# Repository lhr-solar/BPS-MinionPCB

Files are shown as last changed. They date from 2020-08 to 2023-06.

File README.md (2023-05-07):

# BPS Voltage Temperature Minion PCB

## Purpose
This board communicates with the [Leader Board](https://github.com/lhr-solar/BPS-LeaderPCB) over ISOSPI. It is capable of reading up to 12 voltage measurements and 16 temperature measurements. It is also capable of implementing battery balancing through the LTC6811.

## Connectors
* Two 10 pin headers that are used to place the [Minion Hat Board](https://github.com/lhr-solar/BPS-MinionShieldPCB) on top
* Two 7 pin connectors that are used to connect the voltage taps to the board
* Two 2 pin connectors for ISOSPI communication

## BOM
[Mouser cart](https://www.mouser.com/ProjectManager/ProjectDetail.aspx?AccessID=1d4073bff4) of all the components that cannot be sampled.

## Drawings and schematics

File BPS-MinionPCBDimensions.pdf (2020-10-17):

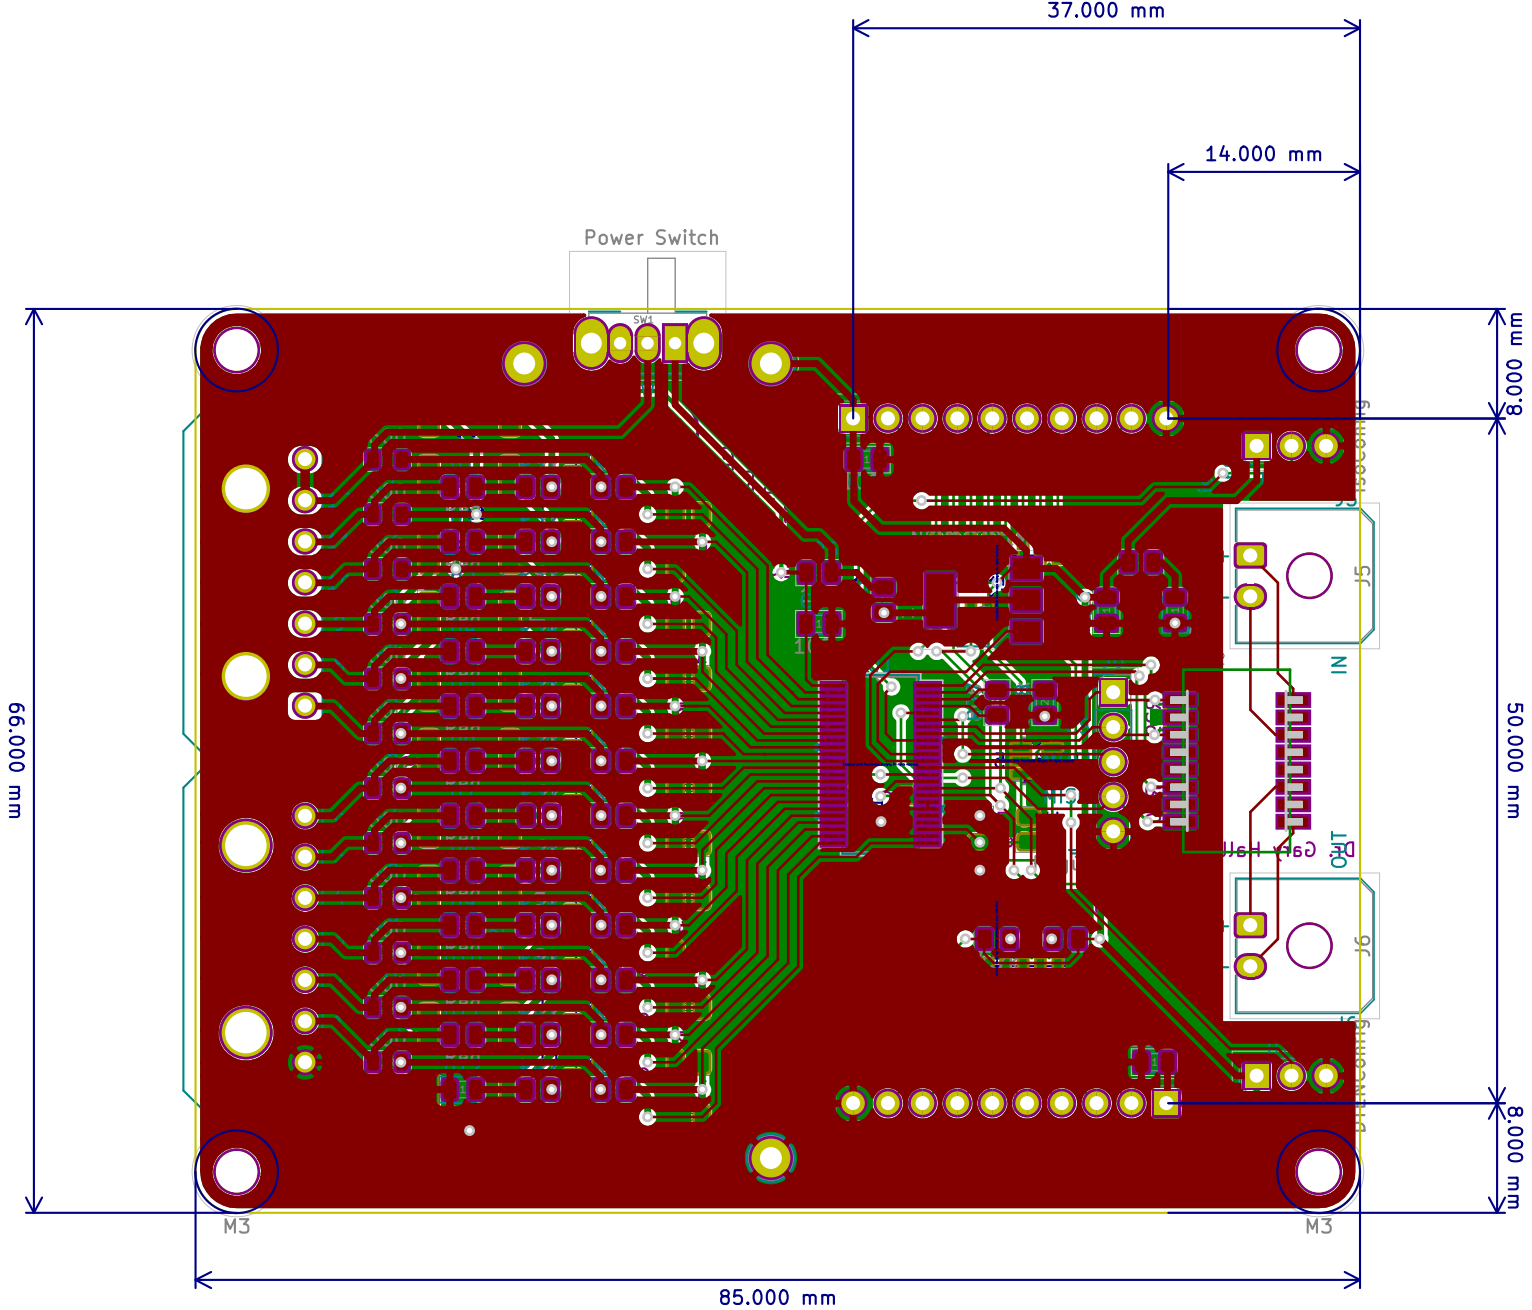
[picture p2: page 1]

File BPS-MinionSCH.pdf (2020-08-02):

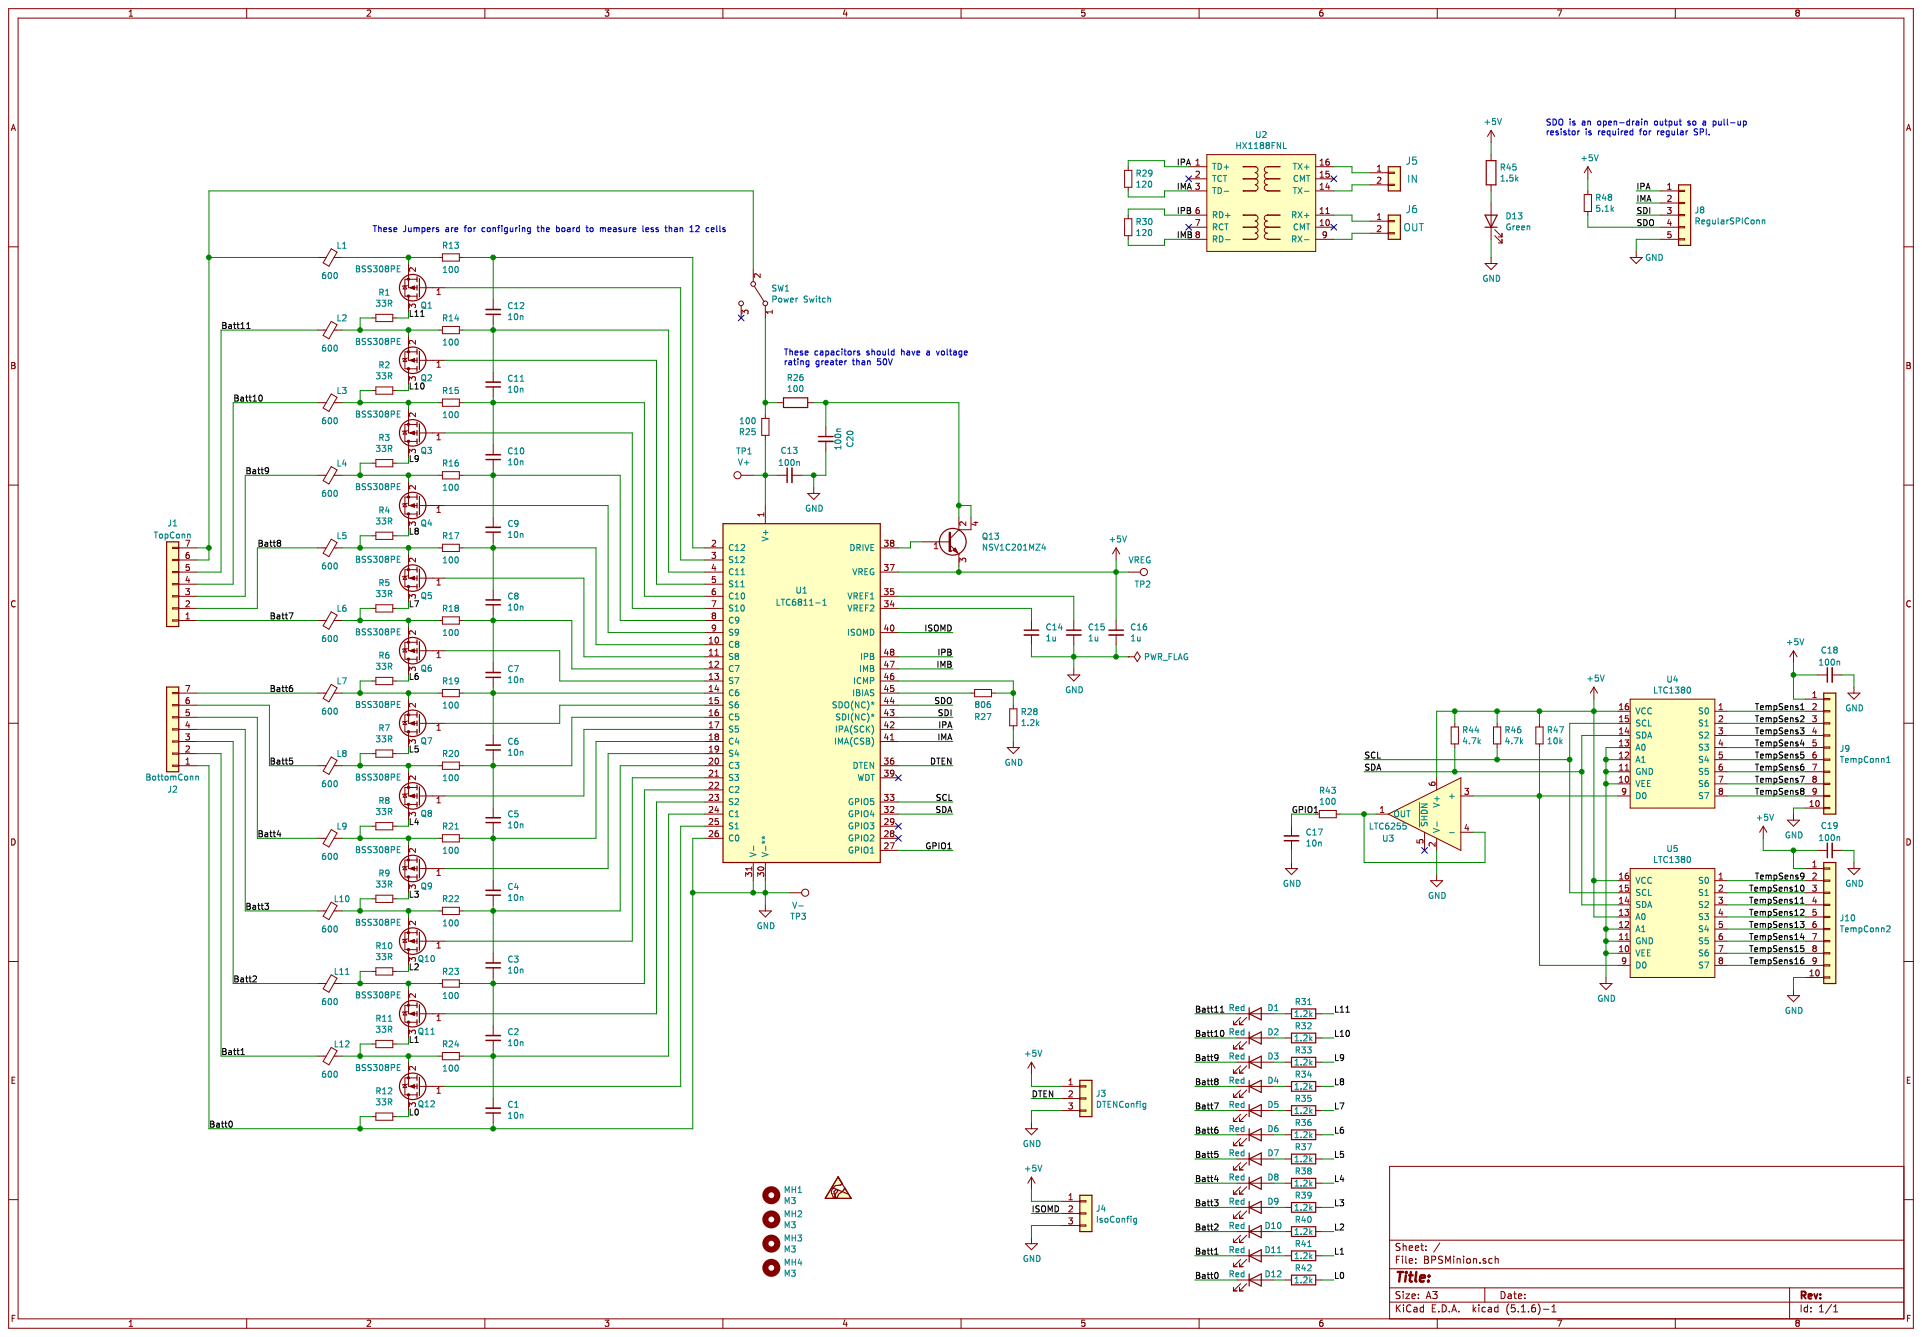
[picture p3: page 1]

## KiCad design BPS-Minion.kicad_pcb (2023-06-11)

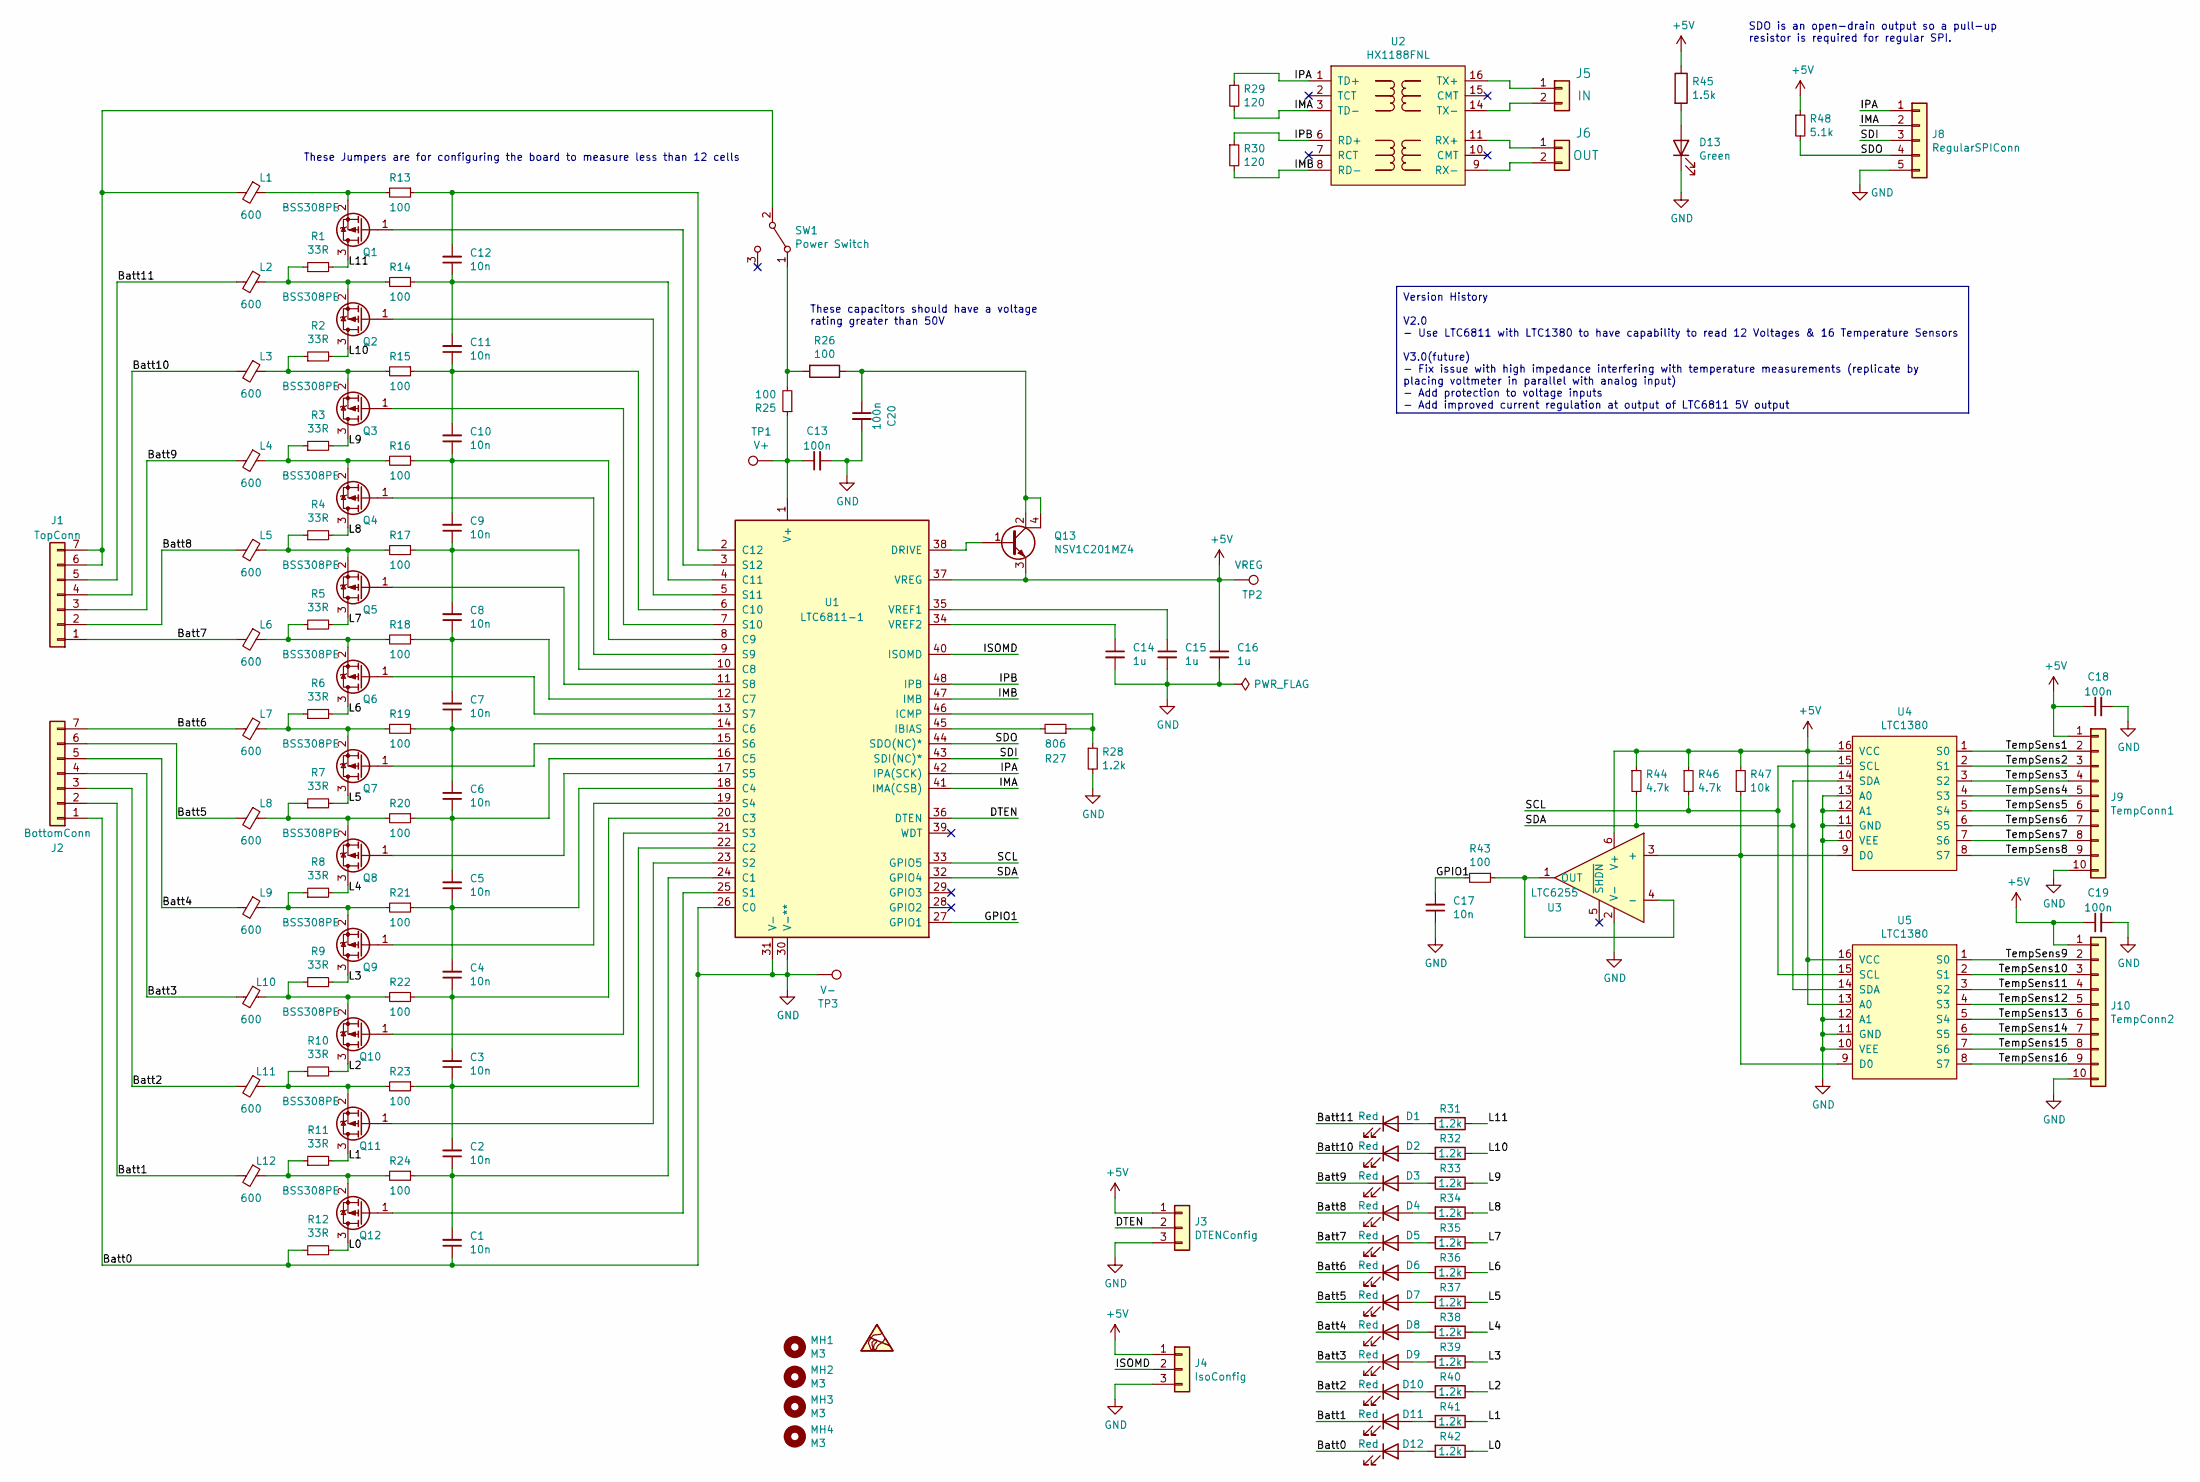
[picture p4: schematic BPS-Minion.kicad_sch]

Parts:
C1, C2, C3, C4, C5, C6, C7, C8, C9, C10, C11, C12, C17: 10n; C_0805_2012Metric
C13, C20: 100n; C_0805_2012Metric; Tolerance 10%; Voltage 100VDC
C14, C15: 1u; C_0805_2012Metric; Tolerance 10%; Voltage 50VDC
C16: 1u; C_0805_2012Metric
C18, C19: 100n; C_0805_2012Metric; Tolerance 10%; Voltage 50VDC
D1, D2, D3, D4, D5, D6, D7, D8, D9, D10, D11, D12: Red; LED_0805_2012Metric
D13: Green; LED_0805_2012Metric
J1: TopConn; Molex_Micro-Fit_3.0_43650-0700_1x07_P3.00mm_Horizontal
J2: BottomConn; Molex_Micro-Fit_3.0_43650-0700_1x07_P3.00mm_Horizontal
J3: DTENConfig; PinHeader_1x03_P2.54mm_Vertical
J4: IsoConfig; PinHeader_1x03_P2.54mm_Vertical
J5: IN; Molex_Micro-Fit_3.0_43650-0200_1x02_P3.00mm_Horizontal
J6: OUT; Molex_Micro-Fit_3.0_43650-0200_1x02_P3.00mm_Horizontal
J8: RegularSPIConn; PinHeader_1x05_P2.54mm_Vertical
J9: TempConn1; PinHeader_1x10_P2.54mm_Vertical
J10: TempConn2; PinHeader_1x10_P2.54mm_Vertical
L1, L2, L3, L4, L5, L6, L7, L8, L9, L10, L11, L12: 600; L_0805_2012Metric
MH1, MH2, MH3, MH4: M3; MountingHole_3mm
Q1, Q2, Q3, Q4, Q5, Q6, Q7, Q8, Q9, Q10, Q11, Q12: BSS308PE; SOT-23
Q13: NSV1C201MZ4; SOT-223
R1, R2, R3, R4, R5, R6, R7, R8, R9, R10, R11, R12: 33R; R_2512_6332Metric
R13, R14, R15, R16, R17, R18, R19, R20, R21, R22, R23, R24, R25, R26, R43: 100; R_0805_2012Metric
R27: 806; R_0805_2012Metric
R28, R31, R32, R33, R34, R35, R36, R37, R38, R39, R40, R41, R42: 1.2k; R_0805_2012Metric
R29, R30: 120; R_0805_2012Metric
R44, R46: 4.7k; R_0805_2012Metric
R45: 1.5k; R_0805_2012Metric
R47: 10k; R_0805_2012Metric
R48: 5.1k; R_0805_2012Metric
SW1: Power Switch; SW_CuK_OS102011MA1QN1_SPDT_Angled
TP1: V+; TestPoint_Keystone_5005-5009_Compact
TP2: VREG; TestPoint_Keystone_5005-5009_Compact
TP3: V-; TestPoint_Keystone_5005-5009_Compact
U1: LTC6811-1; LTC6811HG-1-PBF
U2: HX1188FNL; HXXXX
U3: LTC6255; LTC6255CS6-TRMPBF
U4, U5: LTC1380; LTC1380CS-PBF

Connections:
+5V: C16.1, C18.1, C19.1, J3.1, J4.1, J9.1, J10.1, Q13.3 (E), R44.1, R45.1, R46.1, R47.1, R48.1, TP2.1, U1.37 (VREG), U3.6 (V+), U4.16 (VCC), U5.13 (A0), U5.16 (VCC)
/Batt1: D11.1 (K), J2.2, L12.2
/Batt2: D10.1 (K), J2.3, L11.2
/Batt3: D9.1 (K), J2.4, L10.2
/Batt4: D8.1 (K), J2.5, L9.2
/Batt5: D7.1 (K), J2.6, L8.2
/Batt6: D6.1 (K), J2.7, L7.2
/Batt7: D5.1 (K), J1.1, L6.2
/Batt8: D4.1 (K), J1.2, L5.2
/Batt9: D3.1 (K), J1.3, L4.2
/Batt10: D2.1 (K), J1.4, L3.2
/Batt11: D1.1 (K), J1.5, L2.2
/DTEN: J3.2, U1.36 (DTEN)
/GPIO1: C17.2, R43.2, U1.27 (GPIO1)
/IMA: J8.2, R29.2, U1.41 (IMA(CSB)), U2.3 (TD-)
/IMB: R30.2, U1.47 (IMB), U2.8 (RD-)
/IPA: J8.1, R29.1, U1.42 (IPA(SCK)), U2.1 (TD+)
/IPB: R30.1, U1.48 (IPB), U2.6 (RD+)
/ISOMD: J4.2, U1.40 (ISOMD)
/L0: Q12.3 (D), R12.2, R42.1
/L1: Q11.3 (D), R11.2, R41.1
/L2: Q10.3 (D), R10.2, R40.1
/L3: Q9.3 (D), R9.2, R39.1
/L4: Q8.3 (D), R8.2, R38.1
/L5: Q7.3 (D), R7.2, R37.1
/L6: Q6.3 (D), R6.2, R36.1
/L7: Q5.3 (D), R5.2, R35.1
/L8: Q4.3 (D), R4.2, R34.1
/L9: Q3.3 (D), R3.2, R33.1
/L10: Q2.3 (D), R2.2, R32.1
/L11: Q1.3 (D), R1.2, R31.1
/SCL: R46.2, U1.33 (GPIO5), U4.15 (SCL), U5.15 (SCL)
/SDA: R44.2, U1.32 (GPIO4), U4.14 (SDA), U5.14 (SDA)
/SDI: J8.3, U1.43 (SDI(NC)*)
/SDO: J8.4, R48.2, U1.44 (SDO(NC)*)
/TempSens1: J9.2, U4.1 (S0)
/TempSens2: J9.3, U4.2 (S1)
/TempSens3: J9.4, U4.3 (S2)
/TempSens4: J9.5, U4.4 (S3)
/TempSens5: J9.6, U4.5 (S4)
/TempSens6: J9.7, U4.6 (S5)
/TempSens7: J9.8, U4.7 (S6)
/TempSens8: J9.9, U4.8 (S7)
/TempSens9: J10.2, U5.1 (S0)
/TempSens10: J10.3, U5.2 (S1)
/TempSens11: J10.4, U5.3 (S2)
/TempSens12: J10.5, U5.4 (S3)
/TempSens13: J10.6, U5.5 (S4)
/TempSens14: J10.7, U5.6 (S5)
/TempSens15: J10.8, U5.7 (S6)
/TempSens16: J10.9, U5.8 (S7)
GND: C1.1, C13.2, C14.2, C15.2, C16.2, C17.1, C18.2, C19.2, C20.2, D12.1 (K), D13.1 (K), J2.1, J3.3, J4.3, J8.5, J9.10, J10.10, R12.1, R28.2, TP3.1, U1.26 (C0), U1.30 (V-**), U1.31 (V-), U3.2 (V-), U4.10 (VEE), U4.11 (GND), U4.12 (A1), U4.13 (A0), U5.10 (VEE), U5.11 (GND), U5.12 (A1)
unnamed: C1.2, C2.1, R24.1, U1.24 (C1)
unnamed: C2.2, C3.1, R23.1, U1.22 (C2)
unnamed: C3.2, C4.1, R22.1, U1.20 (C3)
unnamed: C4.2, C5.1, R21.1, U1.18 (C4)
unnamed: C5.2, C6.1, R20.1, U1.16 (C5)
unnamed: C6.2, C7.1, R19.1, U1.14 (C6)
unnamed: C7.2, C8.1, R18.1, U1.12 (C7)
unnamed: C8.2, C9.1, R17.1, U1.10 (C8)
unnamed: C9.2, C10.1, R16.1, U1.8 (C9)
unnamed: C10.2, C11.1, R15.1, U1.6 (C10)
unnamed: C11.2, C12.1, R14.1, U1.4 (C11)
unnamed: C12.2, R13.1, U1.2 (C12)
unnamed: C13.1, R25.1, TP1.1, U1.1 (V+)
unnamed: C14.1, U1.34 (VREF2)
unnamed: C15.1, U1.35 (VREF1)
unnamed: C20.1, Q13.2 (C), Q13.4 (C), R26.1
unnamed: D1.2 (A), R31.2
unnamed: D2.2 (A), R32.2
unnamed: D3.2 (A), R33.2
unnamed: D4.2 (A), R34.2
unnamed: D5.2 (A), R35.2
unnamed: D6.2 (A), R36.2
unnamed: D7.2 (A), R37.2
unnamed: D8.2 (A), R38.2
unnamed: D9.2 (A), R39.2
unnamed: D10.2 (A), R40.2
unnamed: D11.2 (A), R41.2
unnamed: D12.2 (A), R42.2
unnamed: D13.2 (A), R45.2
unnamed: J1.6, J1.7, L1.2, SW1.2 (B)
unnamed: J5.1, U2.16 (TX+)
unnamed: J5.2, U2.14 (TX-)
unnamed: J6.1, U2.11 (RX+)
unnamed: J6.2, U2.9 (RX-)
unnamed: L1.1, Q1.2 (S), R13.2
unnamed: L2.1, Q2.2 (S), R1.1, R14.2
unnamed: L3.1, Q3.2 (S), R2.1, R15.2
unnamed: L4.1, Q4.2 (S), R3.1, R16.2
unnamed: L5.1, Q5.2 (S), R4.1, R17.2
unnamed: L6.1, Q6.2 (S), R5.1, R18.2
unnamed: L7.1, Q7.2 (S), R6.1, R19.2
unnamed: L8.1, Q8.2 (S), R7.1, R20.2
unnamed: L9.1, Q9.2 (S), R8.1, R21.2
unnamed: L10.1, Q10.2 (S), R9.1, R22.2
unnamed: L11.1, Q11.2 (S), R10.1, R23.2
unnamed: L12.1, Q12.2 (S), R11.1, R24.2
unnamed: Q1.1 (G), U1.3 (S12)
unnamed: Q2.1 (G), U1.5 (S11)
unnamed: Q3.1 (G), U1.7 (S10)
unnamed: Q4.1 (G), U1.9 (S9)
unnamed: Q5.1 (G), U1.11 (S8)
unnamed: Q6.1 (G), U1.13 (S7)
unnamed: Q7.1 (G), U1.15 (S6)
unnamed: Q8.1 (G), U1.17 (S5)
unnamed: Q9.1 (G), U1.19 (S4)
unnamed: Q10.1 (G), U1.21 (S3)
unnamed: Q11.1 (G), U1.23 (S2)
unnamed: Q12.1 (G), U1.25 (S1)
unnamed: Q13.1 (B), U1.38 (DRIVE)
unnamed: R25.2, R26.2, SW1.1 (A)
unnamed: R27.1, R28.1, U1.46 (ICMP)
unnamed: R27.2, U1.45 (IBIAS)
unnamed: R43.1, U3.1 (OUT), U3.4 (-)
unnamed: R47.2, U3.3 (+), U4.9 (D0), U5.9 (D0)

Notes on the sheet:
Version History V2.0 - Use LTC6811 with LTC1380 to have capability to read 12 Voltages & 16 Temperature Sensors V3.0(future) - Fix issue with high impedance interfering with temperature measurements (replicate by placing voltmeter in parallel with analog input) - Add protection to voltage inputs - 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
These Jumpers are for configuring the board to measure less than 12 cells
SDO is an open-drain output so a pull-up resistor is required for regular SPI.
These capacitors should have a voltage rating greater than 50V

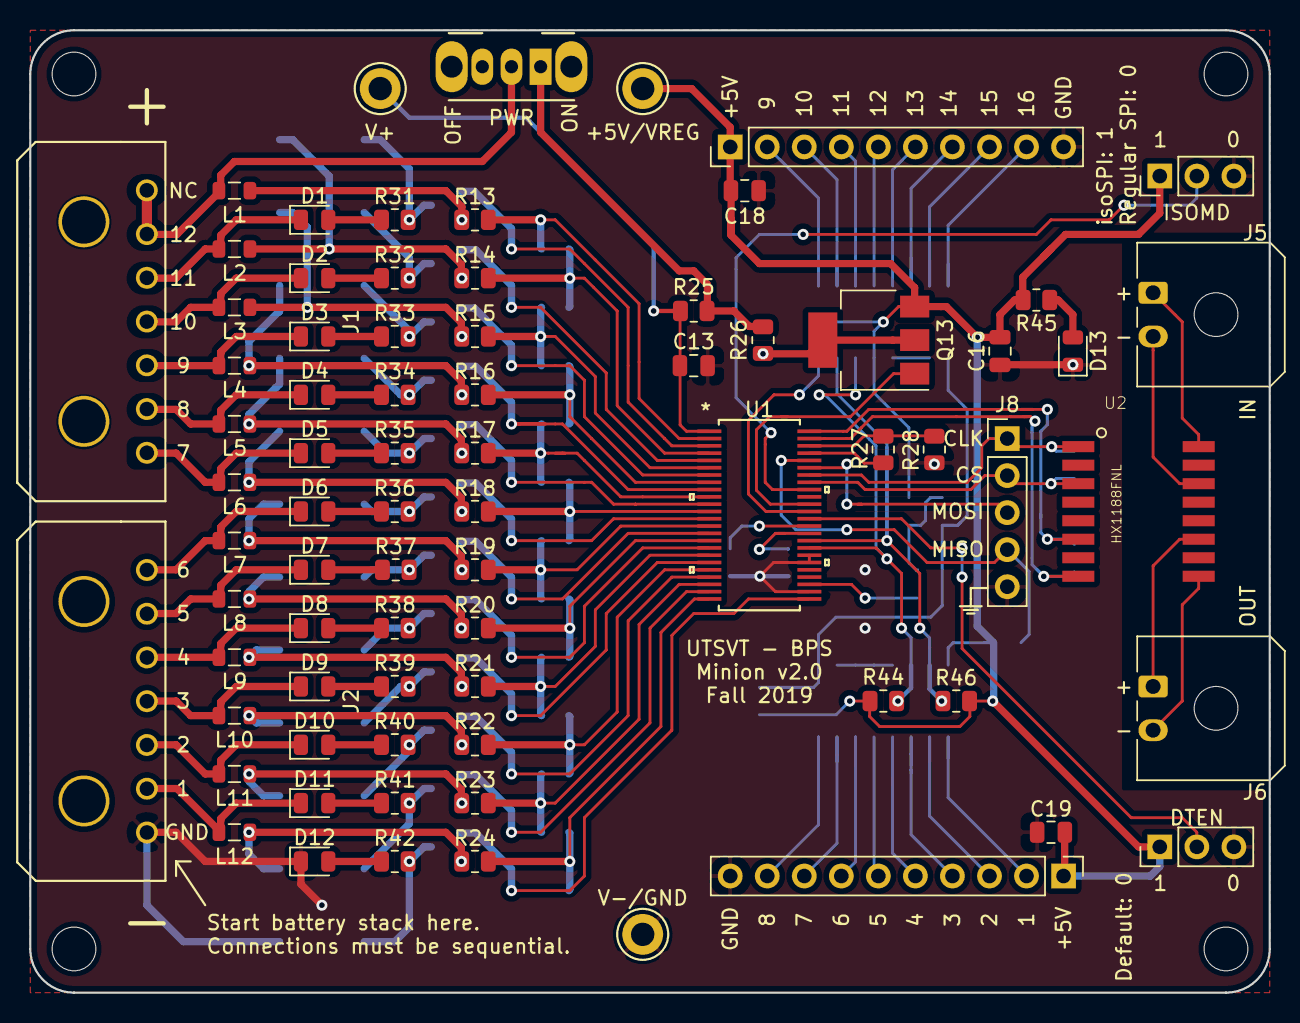
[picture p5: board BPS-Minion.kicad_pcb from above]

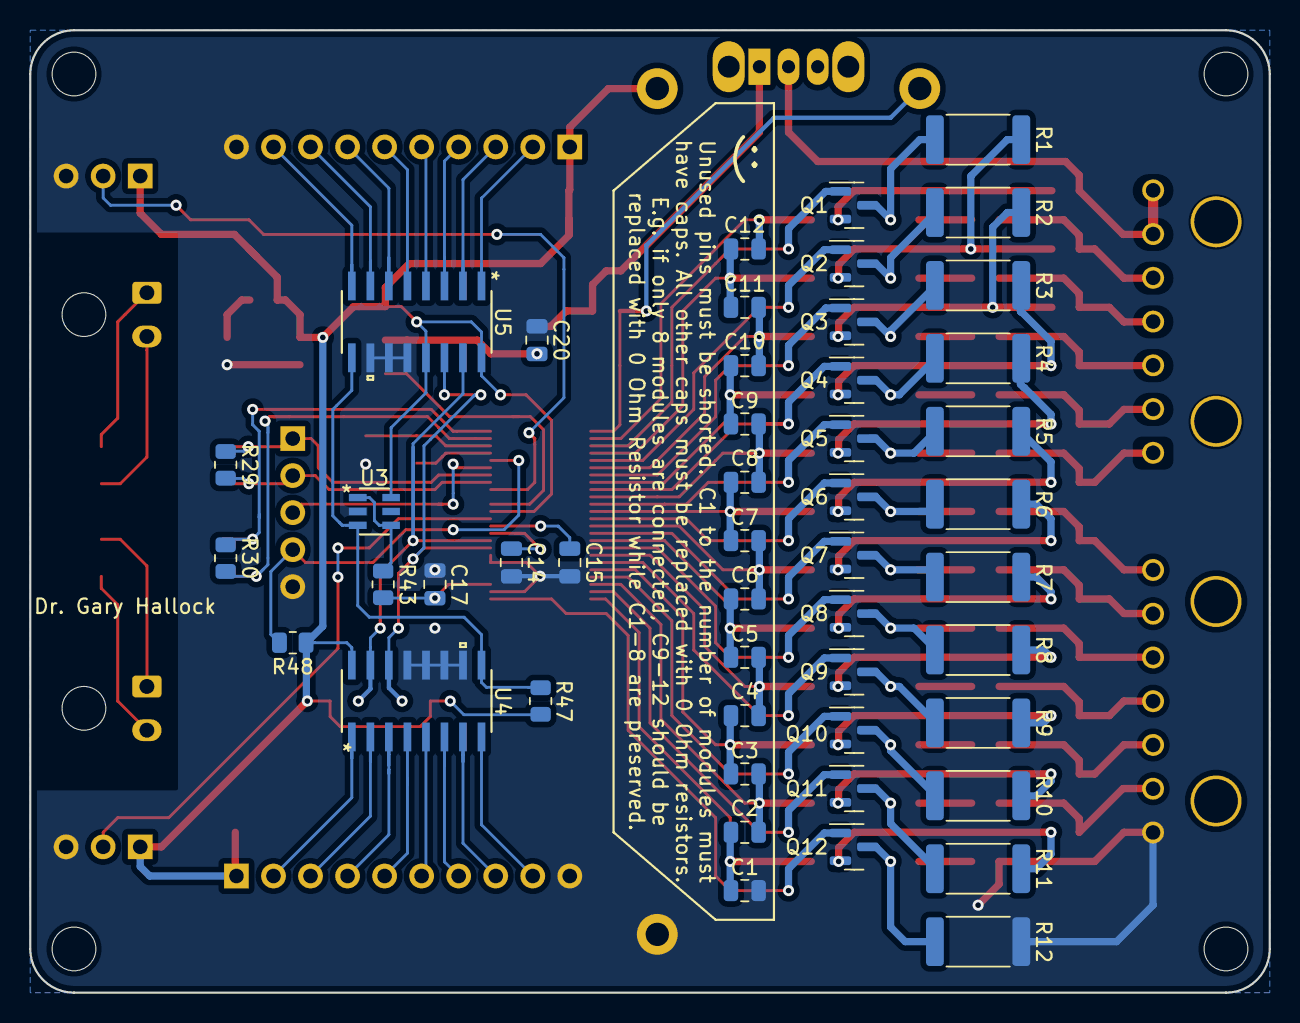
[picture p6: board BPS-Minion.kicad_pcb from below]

Board: 2 copper layers, 85.0 x 66.0 mm, 128 parts (48 on the bottom side), 116 nets.

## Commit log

2020-08-02 Set up for own repository
    [BOM.csv, BPS-Nucleo.kicad_pcb, BPS-Nucleo.sch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]
2020-08-02 Makes sure everything is still good
    [BPSMinion.sch]
2020-08-13 Updates kicad project name to match repo name
    [BPS-MinionPCB.kicad_pcb, BPS-MinionPCB.sch]
2020-09-01 Renames project to not include PCB
    [BPS-Minion.kicad_pcb, BPS-Minion.sch]
2020-09-19 Updates HX1188 to point to common library
    [BPS-Minion.sch]
2020-10-10 Add STEP files. Some connectors still not shown.
    [BPS-Minion.kicad_pcb]
2020-10-17 Adds dimensions and pdf of PCB
    [BPS-Minion.kicad_pcb]
2022-11-12 Added measurements
    [BPS-Minion.kicad_pcb]
2023-05-07 Removed backups, converted to KiCAD 7.0, Added Documentation & version history
    [BPS-Minion.kicad_pcb, BPS-Minion.kicad_sch]
2023-06-11 (Hopefully) finished standardization
    [BPS-Minion.kicad_pcb, BPS-Minion.kicad_sch]
2023-06-11 Moved connector directory
    [BPS-Minion.kicad_pcb]
2023-06-11 Added 3.3V regulator
    [BPS-Minion.kicad_sch]
2023-06-12 Added L431CBT chip + peripherals
    [BPS-Minion.kicad_sch]
2023-06-12 Added can circuit
    [BPS-Minion.kicad_sch]
2023-06-12 Added more questions
    [BPS-Minion.kicad_sch]

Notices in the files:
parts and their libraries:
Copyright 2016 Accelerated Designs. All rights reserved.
